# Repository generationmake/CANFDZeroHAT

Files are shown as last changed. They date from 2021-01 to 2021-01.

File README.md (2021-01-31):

# CANFDZeroHAT
Raspberry Pi HAT with Microchip MCP2517FD or MCP2518FD CAN FD controller

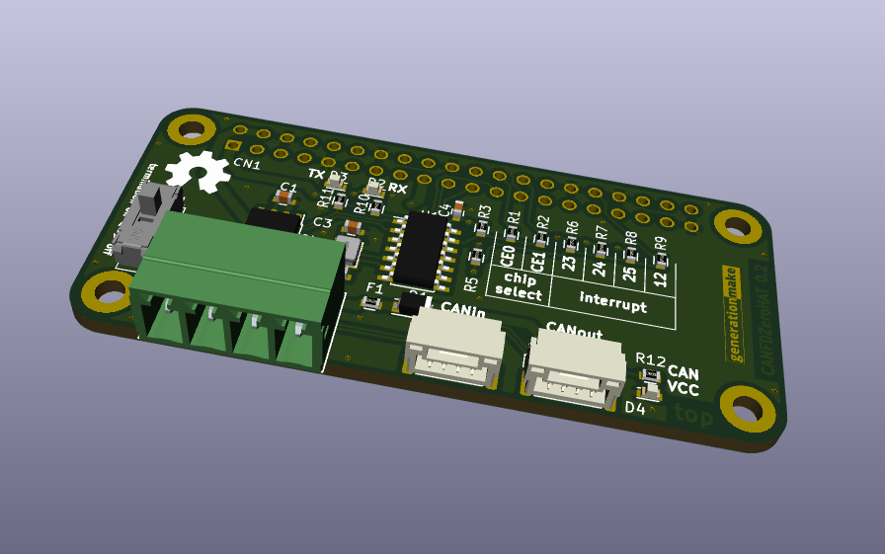
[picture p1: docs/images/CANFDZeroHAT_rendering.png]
CANFDZeroHAT rendering


The board uses a 40 MHz crystal. This is the default crystal for the linux module. The first prototypes used a 20 MHz crystal.

The controller can be connected to SPI0 CE0 or CE1 by populating different resistor jumpers. Also different GPIOs can be used as interrupt.

## setup

edit `/boot/config.txt` and add line:

`dtoverlay=mcp251xfd,spi0-0,interrupt=25`

If you use a crystal different to 40 MHz you have to specify the frequency:

`dtoverlay=mcp251xfd,spi0-0,oscillator=20000000,interrupt=25`

keep care that you choose the right interrupt and SPI CE line and populate the corresponding resistor.

enable CAN after boot up with

`sudo ip link set can0 up type can bitrate 250000`

## connectors

### CAN connector CN2

Terminal block with 3.81 mm grid.

| **Pin** | **Signal** | **Description** |
|:---:|:---:|:---:|
| 1 | GND | |
| 2 | CAN_L | |
| 3 | CAN_H | |
| 4 | VCC | up to 5.5 V |

### UAVCAN dronecode connector CN3 and CN4

compatible to UAVCAN dronecode. JST GH 1.25mm 4-pin.

| **Pin** | **Signal** | **Description** |
|:---:|:---:|:---:|
| 1 | CANVCC | up to 5.5 V |
| 2 | CAN_H | |
| 3 | CAN_L | |
| 4 | GND | |

CANVCC can be connected to the Raspberry Pi via diode D1 as desribed in the dronecode spec. The direction of the diode defines wether current is sourced from the connector or supplied into the UAVCAN system. If no connection is desired just leave D1 unpopulated.

## PCB

### Top

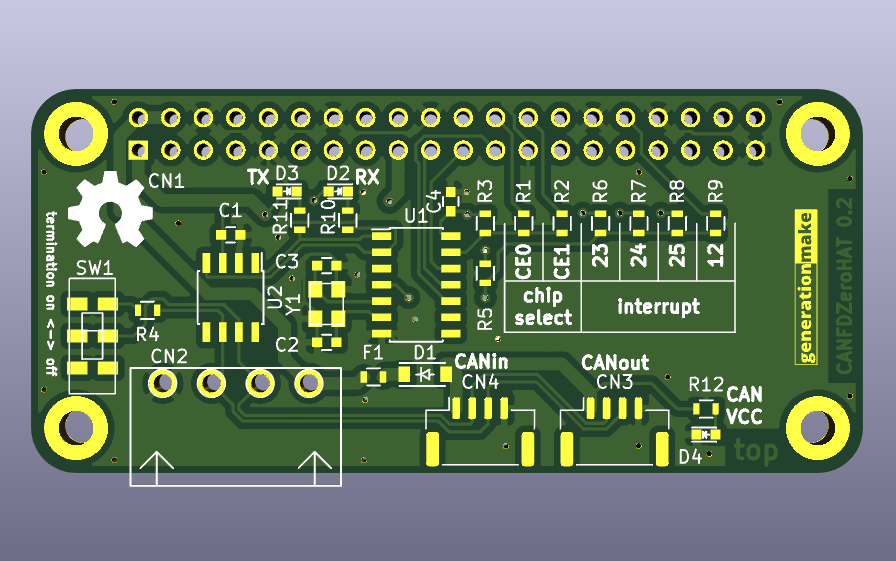
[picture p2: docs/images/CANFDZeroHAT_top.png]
CANFDZeroHAT PCB top


### Bottom

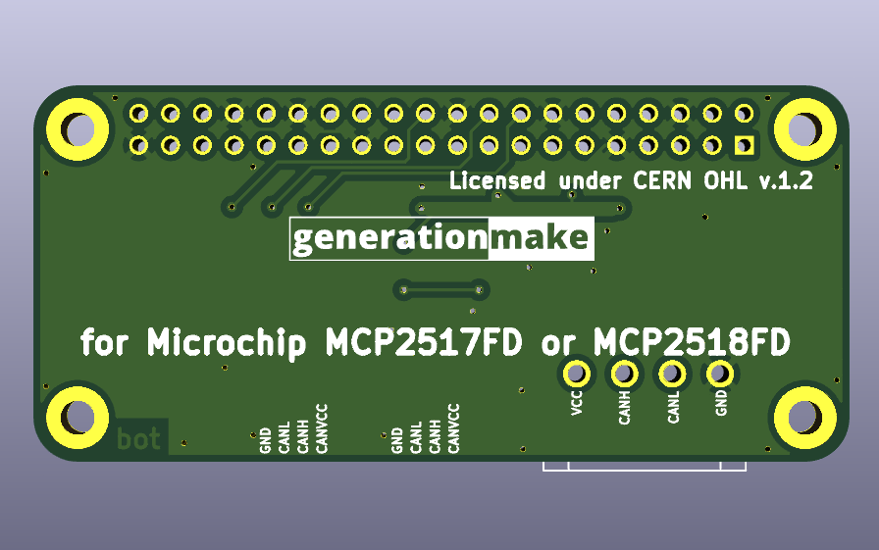
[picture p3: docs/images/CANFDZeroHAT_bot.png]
CANFDZeroHAT PCB bot


## Resources

### Datasheets

 * http://ww1.microchip.com/downloads/en/DeviceDoc/MCP2517FD-External-CAN-FD-Controller-with-SPI-Interface-20005688B.pdf
 * https://ww1.microchip.com/downloads/en/DeviceDoc/External-CAN-FD-Controller-with-SPI-Interface-DS20006027B.pdf

## License

This hardware is licensed under the CERN OHL v. 1.2

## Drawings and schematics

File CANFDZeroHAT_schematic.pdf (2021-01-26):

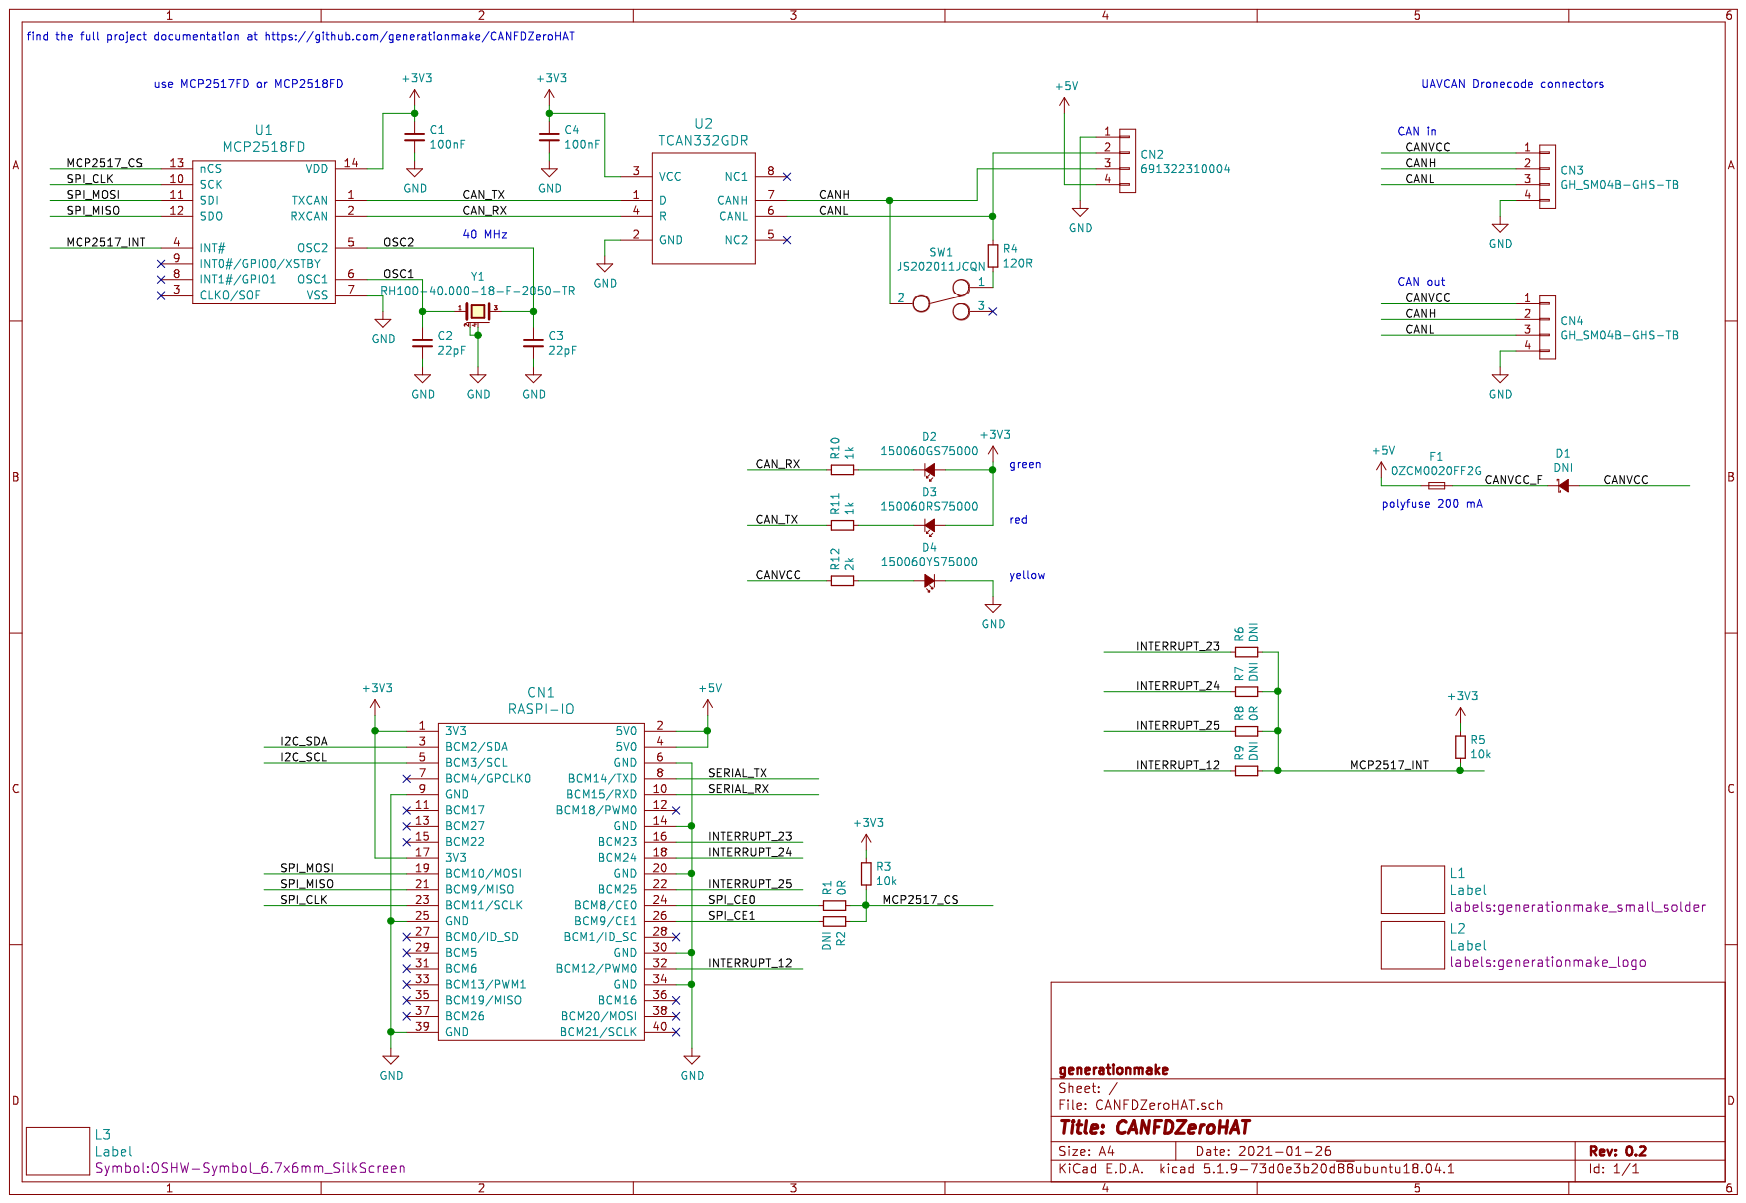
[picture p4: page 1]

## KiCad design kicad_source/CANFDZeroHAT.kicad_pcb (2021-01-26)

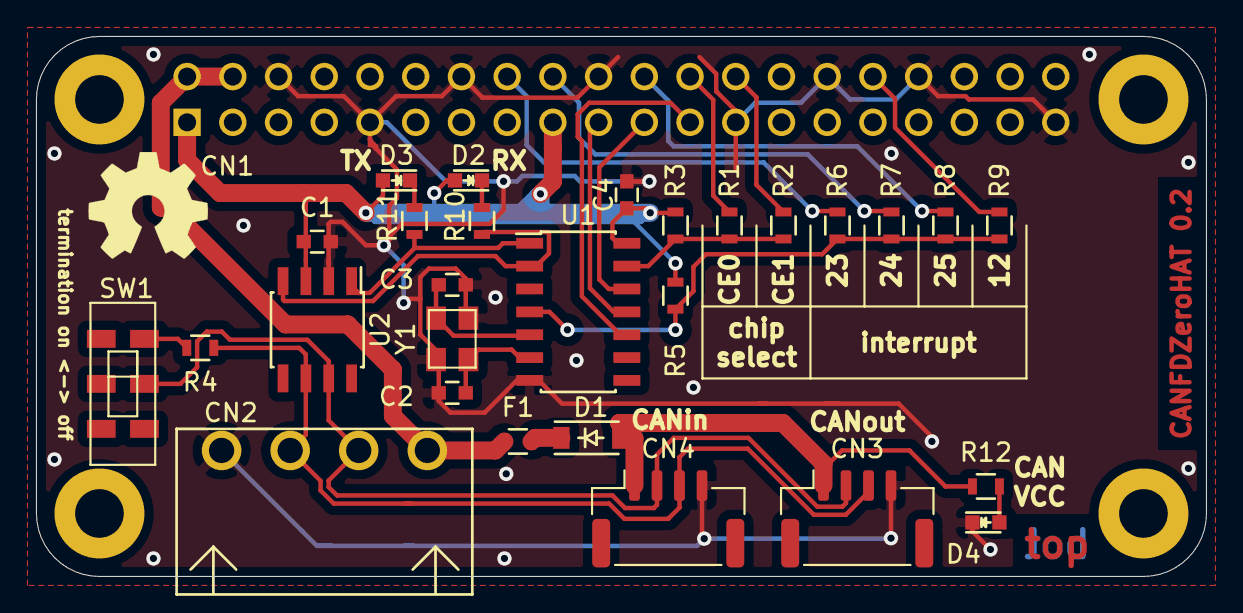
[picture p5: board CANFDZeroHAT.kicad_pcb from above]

Board: 2 copper layers, 65.0 x 30.0 mm, 32 parts (1 on the bottom side), 26 nets.

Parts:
C1, C4: 100nF; C_0603
C2, C3: 22pF; C_0603
CN1: RASPI-IO; RASPI_ZERO_HAT_EDGE
CN2: 691322310004; WR-TBL_691322310004
CN3, CN4: GH_SM04B-GHS-TB; JST_GH_SM04B-GHS-TB_1x04-1MP_P1.25mm_Horizontal
D1: DNI; SOD-123
D2: 150060GS75000; LED_0603
D3: 150060RS75000; LED_0603
D4: 150060YS75000; LED_0603
F1: 0ZCM0020FF2G; R_0603
L1: Label; generationmake_small_solder
L2: Label; generationmake_logo
L3: Label; OSHW-Symbol_6.7x6mm_SilkScreen
R1, R8: 0R; R_0603
R2, R6, R7, R9: DNI; R_0603
R3, R5: 10k; R_0603
R4: 120R; R_0603
R10, R11: 1k; R_0603
R12: 2k; R_0603
SW1: JS202011JCQN; CK_JS202011JCQN
U1: MCP2518FD; SOIC-14_3.9x8.7mm_Pitch1.27mm
U2: TCAN332GDR; SOIC-8_3.9x4.9mm_Pitch1.27mm
Y1: RH100-40.000-18-F-2050-TR; Crystal_SMD_3.2x2.5mm_4Pad

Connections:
+3V3: C1.1, C4.1, CN1.1, CN1.17, D2.2, D3.2, R3.1, R5.1, U1.14, U2.3
+5V: CN1.2, CN1.4, CN2.4, F1.1
/CANH: CN2.3, CN3.2, CN4.2, SW1.2, U2.7
/CANL: CN2.2, CN3.3, CN4.3, R4.1, U2.6
/CANVCC: CN3.1, CN4.1, D1.2, R12.1
/CANVCC_F: D1.1, F1.2
/CAN_RX: R10.1, U1.2, U2.4
/CAN_TX: R11.1, U1.1, U2.1
/INTERRUPT_12: CN1.32, R9.1
/INTERRUPT_23: CN1.16, R6.1
/INTERRUPT_24: CN1.18, R7.1
/INTERRUPT_25: CN1.22, R8.1
/MCP2517_CS: R1.2, R2.1, R3.2, U1.13
/MCP2517_INT: R5.2, R6.2, R7.2, R8.2, R9.2, U1.4
/OSC1: C2.1, U1.6, Y1.1
/OSC2: C3.1, U1.5, Y1.3
/SPI_CE0: CN1.24, R1.1
/SPI_CE1: CN1.26, R2.2
/SPI_CLK: CN1.23, U1.10
/SPI_MISO: CN1.21, U1.12
/SPI_MOSI: CN1.19, U1.11
GND: C1.2, C2.2, C3.2, C4.2, CN1.6, CN1.9, CN1.14, CN1.20, CN1.25, CN1.30, CN1.34, CN1.39, CN2.1, CN3.4, CN4.4, D4.1, U1.7, U2.2, Y1.2, Y1.4
unnamed: D2.1, R10.2
unnamed: D3.1, R11.2
unnamed: D4.2, R12.2
unnamed: R4.2, SW1.1

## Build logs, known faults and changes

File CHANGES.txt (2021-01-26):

CANFDZeroHAT - Raspberry Pi HAT with Microchip MCP2517FD or MCP2518FD CAN FD controller
see full project documentation at https://github.com/generationmake/CANFDZeroHAT

changes

version 0.1 - 2020-12-21
* prototype release

version 0.2 - 2021-01-26
* added fuse and debug leds
* corrected footprint of CAN transceiver
* updated to 40 MHz crystal

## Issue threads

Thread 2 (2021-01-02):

add fuse on CANVCC

generationmake, 2021-01-02:
dronecode standard recommends placing a fuse on CANVCC.
Install a polyfuse.

generationmake, 2021-01-02:
use Bel Fuse 0ZCM0020FF2G 0603
digikey 507-1821-1-ND
https://www.digikey.de/product-detail/de/bel-fuse-inc/0ZCM0020FF2G/507-1821-1-ND/4156270

Closed 2021-01-26.

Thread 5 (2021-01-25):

use correct footprint for CAN transceiver

generationmake, 2021-01-25:
footprint is a little bit to big

Closed 2021-01-26.

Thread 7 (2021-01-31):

add protection on CAN lines

generationmake, 2021-01-31:
add some ESD/EMI protection devices for the CAN bus

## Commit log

2020-12-13 added project from template
    [CANFDZeroHAT.kicad_pcb, CANFDZeroHAT.sch]
2020-12-13 generated schematic and layout
    [CANFDZeroHAT.kicad_pcb, CANFDZeroHAT.sch]
2020-12-18 added option resistors, updated layout
    [CANFDZeroHAT.kicad_pcb, CANFDZeroHAT.sch]
2020-12-18 updated some part numbers
    [CANFDZeroHAT.kicad_pcb, CANFDZeroHAT.sch]
2020-12-20 added pdf schematic
    [CANFDZeroHAT.sch]
2020-12-20 added images, updated readme
    [CANFDZeroHAT.kicad_pcb]
2021-01-02 updated schematic, added fuse and debug leds
    [CANFDZeroHAT.sch]
2021-01-02 updated layout
    [CANFDZeroHAT.kicad_pcb, CANFDZeroHAT.sch]
2021-01-25 corrected footprint of CAN transceiver
    [CANFDZeroHAT.kicad_pcb, CANFDZeroHAT.sch]
2021-01-25 updated 40 MHz crystal
    [CANFDZeroHAT.kicad_pcb, CANFDZeroHAT.sch]
2021-01-26 made debug leds low active
    [CANFDZeroHAT.kicad_pcb, CANFDZeroHAT.sch]
2021-01-26 updated labels
    [CANFDZeroHAT.kicad_pcb, CANFDZeroHAT.sch]
2021-01-26 updated schematic pdf and images
2021-01-26 added 3d model of board

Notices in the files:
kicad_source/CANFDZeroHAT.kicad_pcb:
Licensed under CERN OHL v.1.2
